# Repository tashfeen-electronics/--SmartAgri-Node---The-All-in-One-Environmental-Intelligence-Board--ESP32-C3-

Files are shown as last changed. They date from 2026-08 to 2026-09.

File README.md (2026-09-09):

# 🌾 SmartAgri Node — The All-in-One Environmental Intelligence Board— ESP32-C3 Environmental Monitoring PCB

A custom 4-layer PCB designed in KiCad for smart agriculture and environmental data logging — built around the **ESP32-C3-WROOM-02-H4**, with onboard sensing, local storage, and off-grid power management.






---

## 🚀 Overview

## 🌾 SmartAgri Node — The All-in-One Environmental Intelligence Board

*A masterclass in compact IoT engineering — built for the field, engineered for the future.*

Powered by the **ESP32-C3-WROOM-02-H4**, this board isn't just a sensor node — it's a complete edge-computing ecosystem packed into a single, elegant design. Whether you're building smart farms, weather networks, or next-gen IoT products, this board is your foundation.

### 🚀 Flagship Applications

- **🌱 Precision Agriculture Systems** — Real-time climate intelligence (temp, humidity, pressure, light) empowers farmers to optimize irrigation, planting, and harvest cycles like never before
- **☀️ Off-Grid Solar Monitoring Stations** — Autonomous, self-charging design (USB-C + battery + MCP73871 power management) means true "install and forget" reliability in remote locations
- **📡 Enterprise-Grade IoT Weather Networks** — Wi-Fi/BLE connectivity turns every unit into a live data point in a scalable, cloud-connected sensor mesh
- **💾 Mission-Critical Data Logging** — Onboard microSD ensures zero data loss, even in connectivity dead zones — perfect for research-grade field studies
- **🔊 Smart Environmental Surveillance** — Integrated mic input opens doors to acoustic monitoring: pest detection, livestock sounds, equipment health diagnostics
- **🔆 Intelligent Light Management** — TEMT6000 sensor enables automated greenhouse shading, grow-light control, and crop exposure analytics
- **🔌 Plug-and-Play Expansion Platform** — I2C/GPIO breakout headers make this a launchpad for custom sensor arrays: soil moisture, pH, EC, CO2, and beyond
- **🛡️ Industrial-Grade Power Protection** — ESD protection, fuse safeguarding, and regulated 3.3V rail deliver rock-solid reliability in harsh outdoor conditions
- **☁️ OTA-Ready Firmware Architecture** — Onboard SPI flash means remote fleets can be updated instantly — no truck rolls, no manual reflashing
- **🎓 Premier Prototyping & Education Platform** — USB-C programming, dedicated BOOT/RESET buttons, and SPI test points make this the go-to dev board for makers, students, and R&D teams alike

### 💎 Why This Board Stands Out

One design. Ten industries. Infinite possibilities — from **precision farming** to **smart cities**, **environmental research** to **industrial IoT**. This isn't just a PCB — it's a **scalable platform** ready to power the next generation of connected, autonomous sensing solutions.

---

## 🌾 Applications

- **Smart agriculture field monitoring** — logs temperature, humidity, pressure, and light intensity across crop fields or greenhouses
- **Solar/battery-powered remote sensor node** — runs unattended in the field, rechargeable via USB-C or solar panel
- **Soil/climate data logging station** — SD card backup for areas with weak or no Wi-Fi coverage
- **IoT weather station** — pushes live BME280 readings to a cloud dashboard or local server
- **Sunlight exposure tracking** — monitors sun exposure for crop growth optimization
- **Acoustic/pest monitoring** — mic input can detect insect activity, animal presence, or equipment sound
- **Expandable sensor hub** — I2C/GPIO headers for adding soil moisture, pH, or EC sensors
- **Battery-backed edge logger** — continues sensing during power outages or disconnection
- **OTA-capable firmware node** — onboard SPI flash supports remote firmware updates
- **General-purpose outdoor IoT dev board** — reusable prototyping platform beyond agriculture

---

## 🧩 Hardware Overview

### 🧠 Core Processing & Connectivity
| Component | Part | Purpose |
|---|---|---|
| U3 | ESP32-C3-WROOM-02-H4 | Main MCU — Wi-Fi/BLE, RISC-V core, chosen for wireless field data transmission without an external radio module |
| U4 | CP2102N | USB-to-UART bridge for programming/serial debug over USB-C |
| U2 | W25Q32JVSSIQ (32Mbit SPI Flash) | Extra non-volatile storage for OTA updates and log buffering |
| J3 | GSD090012SEU (microSD slot) | Local offline data logging when Wi-Fi is unavailable |

### 🌡️ Sensors
| Component | Part | Purpose |
|---|---|---|
| U6 | BME280 | Temperature, humidity & barometric pressure sensing |
| Q1 | TEMT6000X01 | Ambient light intensity sensing for crop exposure analysis |
| U7 | MAX4466EXK | Mic amplifier for acoustic sensing (pest/environmental sound) |

### 🔋 Power Management
| Component | Part | Purpose |
|---|---|---|
| J1 | USB-C (2338792-1) | Primary power/data input |
| J2 | JST connector (B2B-PH-SM4-TB) | Li-ion/LiPo battery input |
| U1 | MCP73871 | Battery charge management + power path — charges while running on USB |
| VR1 | LM1117MPX-3.3 | Regulates supply to a clean 3.3V rail |
| U5 | USBLC6-2SC6 | ESD protection on USB data lines |
| F1 | 0ZCH0110AF2E | Resettable fuse — overcurrent protection |
| Q2, Q3 | BC817 | Power switching/load gating for sleep-mode power savings |
| MK1 | CMC-5042PF-AC | Inductor/choke for power line filtering |

### 🕹️ User Interface
| Component | Part | Purpose |
|---|---|---|
| S1 | BOOT button | Puts ESP32 into flashing/bootloader mode |
| S2 | RESET button | Manual MCU reset |
| D1, D5 | Blue LEDs | Status indicators |
| D2, D6 | Green LEDs | Status indicators |
| D3, D4 | Red LEDs | Fault/error indicators |

### 🔧 Debug & Expansion
| Component | Purpose |
|---|---|
| TP1–TP5 | SPI bus test points (MOSI, MISO, SCLK, CS, CS-SD) for debugging flash/SD card |
| J4 | 4-pin header — I2C expansion (GND/SCL/SDA/3.3V) for external sensors |
| J5 | 5-pin header — additional GPIO/power expansion |

### ⚙️ Passives
- **Capacitors (C1–C25):** Decoupling and bulk capacitance for clean power delivery, especially during Wi-Fi transmit bursts
- **Resistors (R1–R35):** Pull-ups (I2C/reset lines), LED current limiting, and voltage divider/feedback networks

---

## 🧱 PCB Stackup — Why 4 Layers?

This board uses a **4-layer stackup (Signal / GND / PWR / Signal)** instead of a simpler 2-layer design, chosen specifically for better signal integrity given the mix of RF, digital, analog, and power circuitry on one small board.

**Benefits realized:**
- ✅ Dedicated, uninterrupted ground plane — critical for ESP32-C3 RF performance and reducing noise coupling into analog sensors
- ✅ Shorter, controlled return paths for high-speed SPI signals (flash + SD card), reducing EMI and reflections
- ✅ Dedicated power plane for cleaner, lower-impedance power delivery — especially during Wi-Fi TX current spikes
- ✅ Better isolation between noisy switching regulator circuitry and sensitive analog front-end (mic amp, light sensor)
- ✅ Tighter, more professional routing without sacrificing signal quality

---

## 🛠️ Tools Used

- **KiCad** — schematic capture, PCB layout, and 3D visualization

---

## 📸 Board Preview

*(Add board render/photo here)*

---

## 📋 Bill of Materials

Full BOM with quantities and footprints is available in <a href="https://github.com/tashfeen-electronics/--SmartAgri-Node---The-All-in-One-Environmental-Intelligence-Board--ESP32-C3-/blob/main/ESP32%20Project/bom/ibom.html" class="button">BOM</a>

---

## 📄 License

<a href="https://github.com/tashfeen-electronics/--SmartAgri-Node---The-All-in-One-Environmental-Intelligence-Board--ESP32-C3-/blob/main/LICENSE" class="button">
  ***LICENSE***
</a>

---

## 🙌 Author

**Tashfeen Electronics**
Designed with ❤️ in KiCad

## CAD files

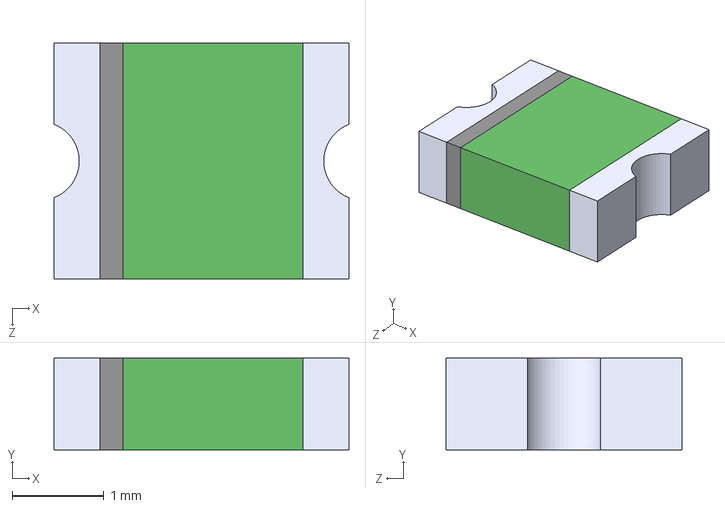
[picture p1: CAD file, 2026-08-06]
ESP32 Project/Symbol and footprint libraries for esp32 project/0ZCH0110AF2E/0ZCH0110AF2E.step
3.21 x 1.00 x 2.58 mm

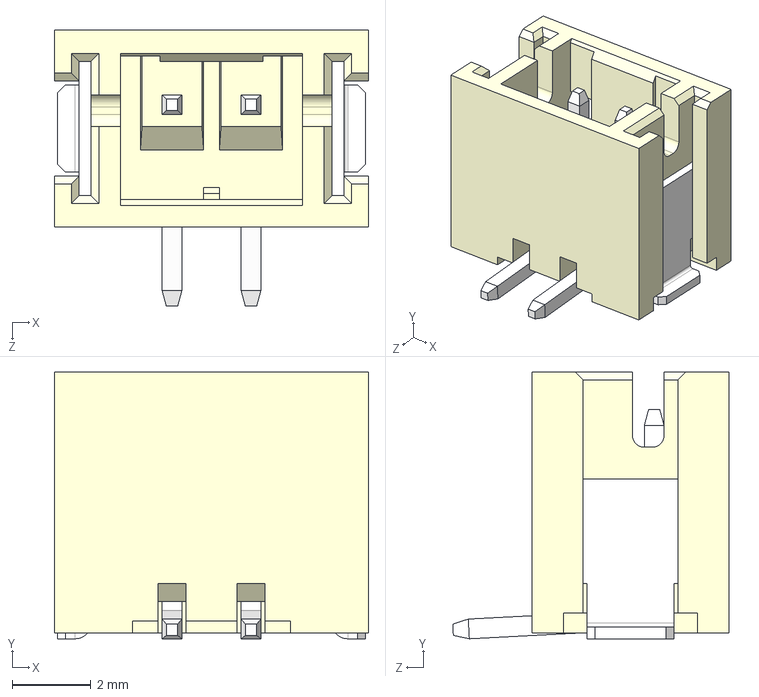
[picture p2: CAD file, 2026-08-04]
ESP32 Project/Symbol and footprint libraries for esp32 project/B2B-PH-SM4-TB/B2B-PH-SM4-TB.step
7.95 x 6.75 x 7.00 mm

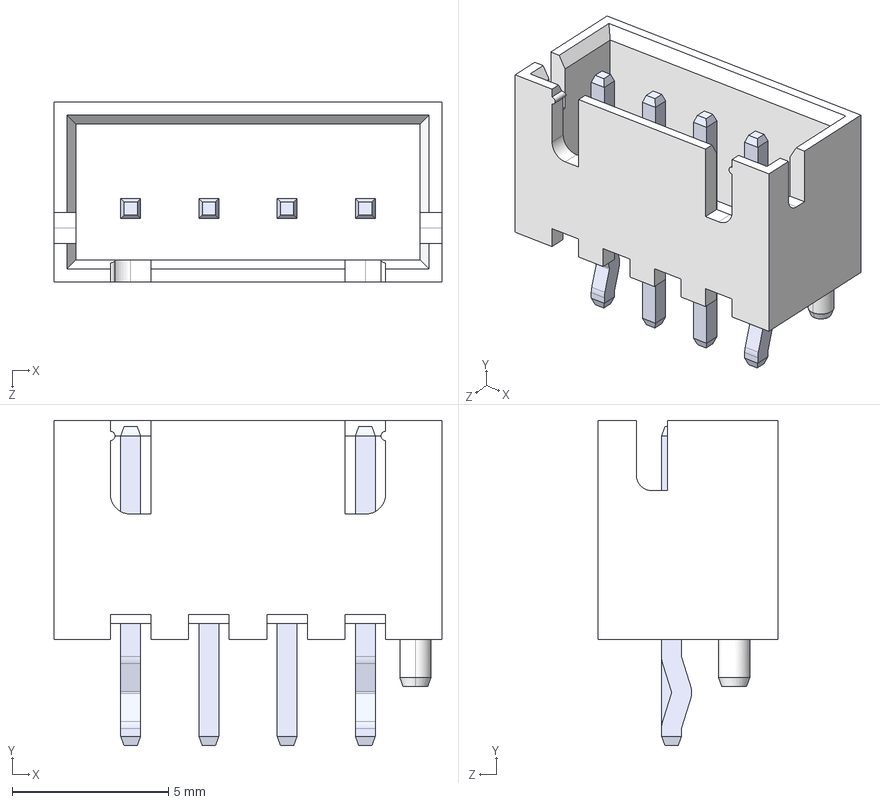
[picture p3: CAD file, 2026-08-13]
ESP32 Project/Symbol and footprint libraries for esp32 project/B4B-XH-AM__LF__SN_/B4B-XH-AM__LF__SN_.step
12.4 x 10.4 x 5.75 mm

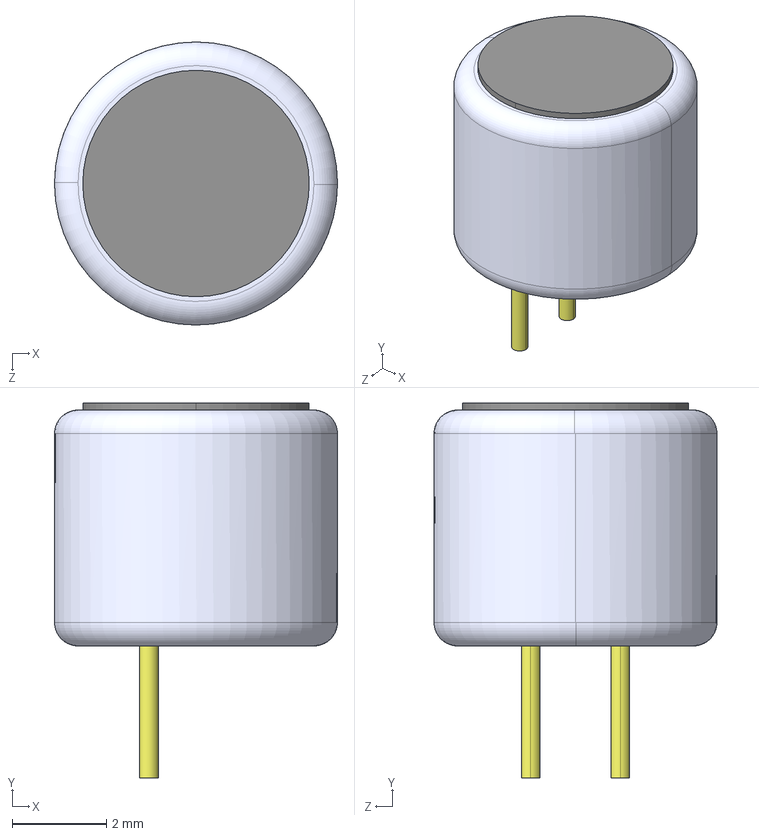
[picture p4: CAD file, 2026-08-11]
ESP32 Project/Symbol and footprint libraries for esp32 project/CMC-5042PF-AC/CMC-5042PF-AC.step
6.00 x 7.95 x 6.00 mm

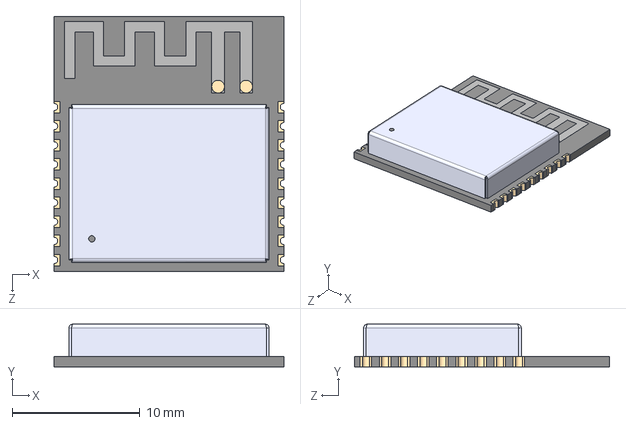
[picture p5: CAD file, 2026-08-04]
ESP32 Project/Symbol and footprint libraries for esp32 project/Esp32 c3 wroom 02/ESP32-C3-WROOM-02-H4.step
18.0 x 3.35 x 20.0 mm

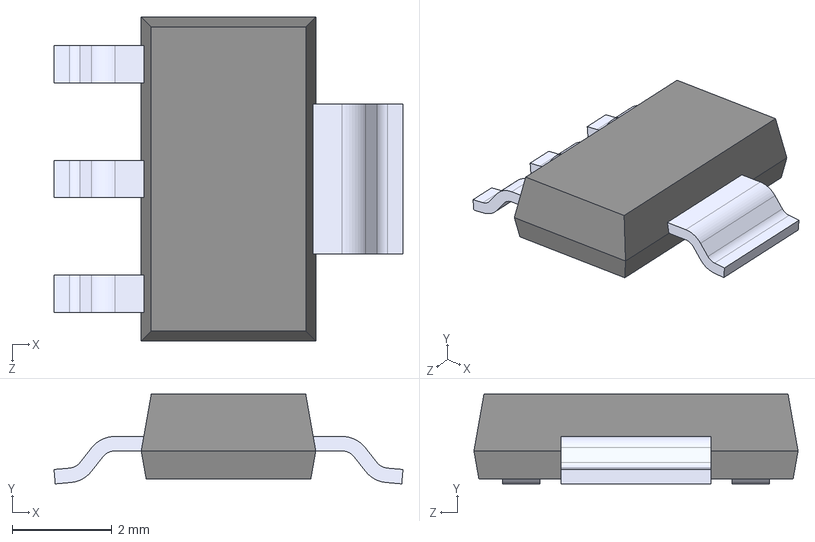
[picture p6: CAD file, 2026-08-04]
ESP32 Project/Symbol and footprint libraries for esp32 project/LM1117MPX-3.3/LM1117MPX-3.3.step
7.00 x 1.80 x 6.50 mm

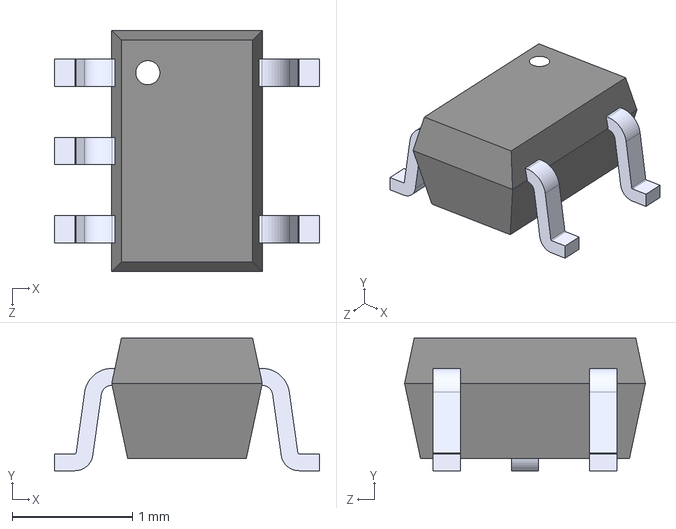
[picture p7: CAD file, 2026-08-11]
ESP32 Project/Symbol and footprint libraries for esp32 project/MAX4466EXK/MAX4466EXK.step
2.20 x 1.10 x 2.00 mm

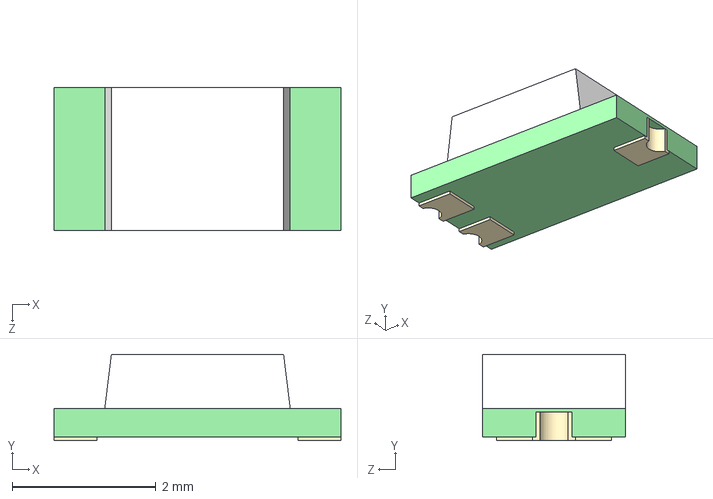
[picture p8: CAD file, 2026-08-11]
ESP32 Project/Symbol and footprint libraries for esp32 project/TEMT6000X01/TEMT6000X01.step
4.00 x 1.20 x 2.00 mm

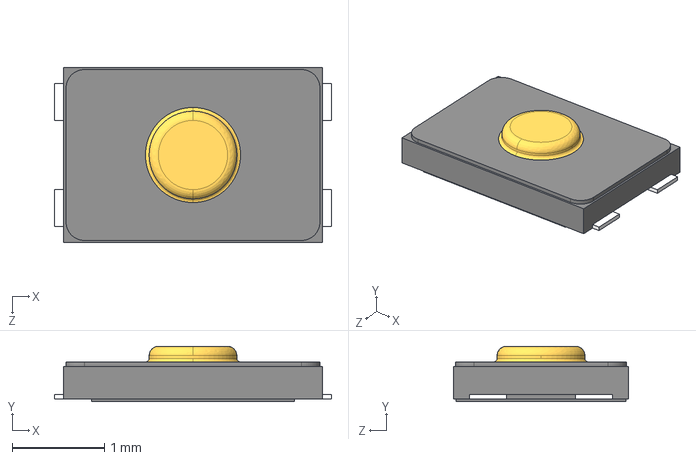
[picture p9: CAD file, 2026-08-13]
ESP32 Project/Symbol and footprint libraries for esp32 project/USLPT2819DT2TR/USLPT2819DT2TR.step
3.00 x 0.6 x 1.90 mm

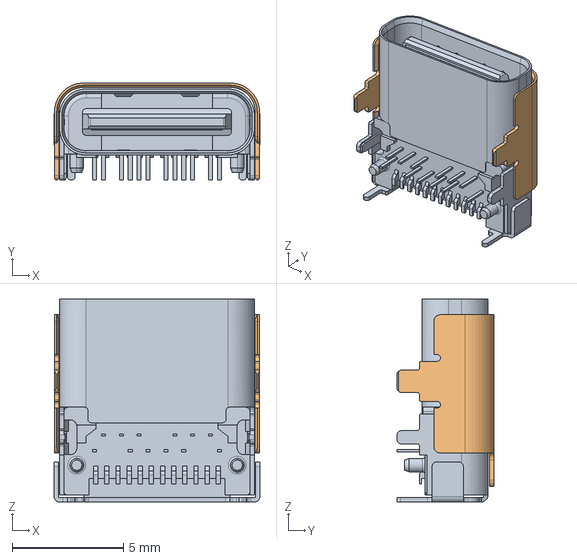
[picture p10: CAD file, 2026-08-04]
ESP32 Project/Symbol and footprint libraries for esp32 project/2338792-1/2338792-1.step
9.24 x 4.35 x 9.10 mm

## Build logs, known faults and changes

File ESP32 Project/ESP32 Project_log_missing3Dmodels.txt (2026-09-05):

[('U4', 'E:\\KICAD v10.4\\share\\kicad\\3dmodels\\Package_DFN_QFN.3dshapes\\QFN-20-1EP_3x3mm_P0.45mm_EP1.6x1.6mm.step')]

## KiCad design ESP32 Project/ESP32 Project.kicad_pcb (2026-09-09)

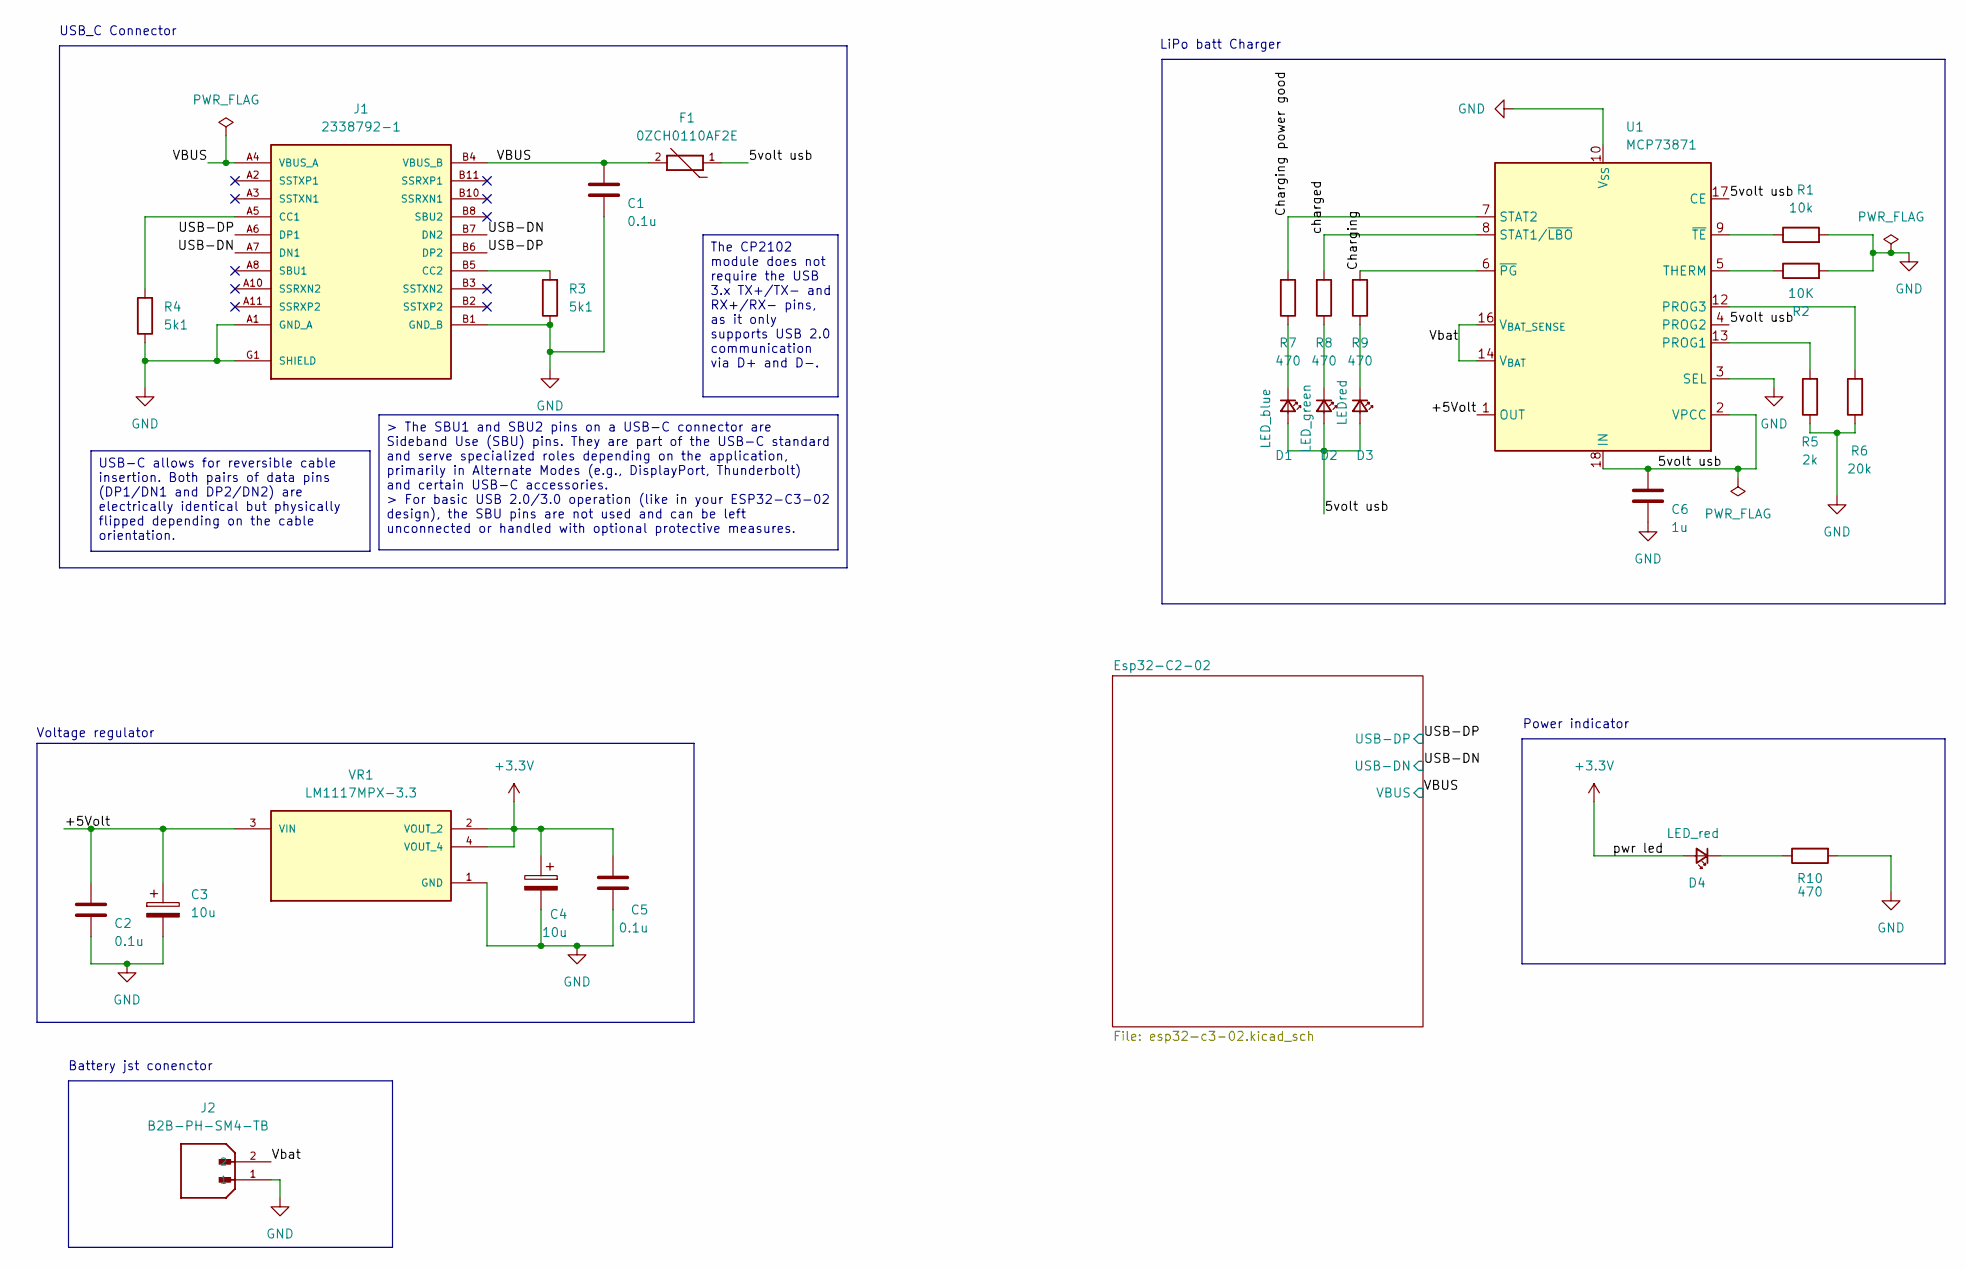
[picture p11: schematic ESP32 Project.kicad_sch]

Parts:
C1, C2, C5: 0.1u; C_0805_2012Metric
C3, C4: 10u; CP_EIA-3216-12_Kemet-S
C6: 1u; C_0805_2012Metric
D1: LED_blue; LED_0805_2012Metric_Pad1.15x1.40mm_HandSolder
D2: LED_green; LED_0805_2012Metric_Pad1.15x1.40mm_HandSolder
D3: LEDred; LED_0805_2012Metric_Pad1.15x1.40mm_HandSolder
D4: LED_red; LED_0805_2012Metric_Pad1.15x1.40mm_HandSolder
F1: 0ZCH0110AF2E; FUSC3225X100N; PARTREV Apr2023
J1: 2338792-1; TE_2338792-1; PARTREV A1
J2: B2B-PH-SM4-TB; JST_B2B-PH-SM4-TB; PARTREV N/A
R1: 10k; R_0805_2012Metric
R2: 10K; R_0805_2012Metric
R3, R4: 5k1; R_0805_2012Metric
R5: 2k; R_0805_2012Metric
R6: 20k; R_0805_2012Metric
R7, R8, R9, R10: 470; R_0805_2012Metric
U1: MCP73871; QFN-20-1EP_4x4mm_P0.5mm_EP2.5x2.5mm
VR1: LM1117MPX-3.3; VREG_LM1117MPX-3.3; PARTREV O

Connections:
+3.3V: C4.1, C5.1, D4.2 (A), VR1.2 (VOUT_2), VR1.4 (VOUT_4); also elsewhere on the board
/5volt usb: C6.1, D1.2 (A), D2.2 (A), D3.2 (A), F1.1, U1.2 (VPCC), U1.4 (PROG2), U1.17 (CE), U1.18 (IN), U1.19 (IN)
/+5Volt: C2.1, C3.1, U1.1 (OUT), U1.20 (OUT), VR1.3 (VIN)
/Charging: R9.2, U1.6 (~PG)
/Charging power good: R7.2, U1.7 (STAT2)
/USB-DN: J1.A7 (DN1), J1.B7 (DN2); also elsewhere on the board
/USB-DP: J1.A6 (DP1), J1.B6 (DP2); also elsewhere on the board
/Vbat: J2.2, U1.14 (V_{BAT}), U1.15 (V_{BAT}), U1.16 (V_{BAT_SENSE})
/charged: R8.2, U1.8 (STAT1/~LBO)
GND: C1.2, C2.2, C3.2, C4.2, C5.2, C6.2, J1.A1 (GND_A), J1.A12 (GND_A), J1.B1 (GND_B), J1.B12 (GND_B), J1.G1 (SHIELD), J1.G2 (SHIELD), J1.G3 (SHIELD), J1.G4 (SHIELD), J1.G5 (SHIELD), J1.G6 (SHIELD), J2.1, R1.2, R2.2, R3.1, R4.1, R5.1, R6.1, R10.2, U1.3 (SEL), U1.10 (V_{SS}), U1.11 (V_{SS}), U1.21 (V_{SS}), VR1.1 (GND); also elsewhere on the board
unnamed: D1.1 (K), R7.1
unnamed: D2.1 (K), R8.1
unnamed: D3.1 (K), R9.1
unnamed: D4.1 (K), R10.1
unnamed: J1.A5 (CC1), R4.2
unnamed: J1.B5 (CC2), R3.2
unnamed: R5.2, U1.13 (PROG1)
unnamed: R6.2, U1.12 (PROG3)
unnamed: R2.1, U1.5 (THERM)
unnamed: R1.1, U1.9 (~TE)
VBUS_A: C1.1, F1.2, J1.A4 (VBUS_A), J1.A9 (VBUS_A), J1.B4 (VBUS_B), J1.B9 (VBUS_B); also elsewhere on the board

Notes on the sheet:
Power indicator
USB_C Connector
Voltage regulator
LiPo batt Charger
Battery jst conenctor
USB-C allows for reversible cable insertion. Both pairs of data pins (DP1/DN1 and DP2/DN2) are electrically identical but physically flipped depending on the cable orientation.
The CP2102 module does not require the USB 3.x TX+/TX- and RX+/RX- pins, as it only supports USB 2.0 communication via D+ and D-.
> The SBU1 and SBU2 pins on a USB-C connector are Sideband Use (SBU) pins. They are part of the USB-C standard and serve specialized roles depending on the application, primarily in Alternate Modes (e.g., DisplayPort, Thunderbolt) and certain USB-C accessories. > For basic USB 2.0/3.0 operation (li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

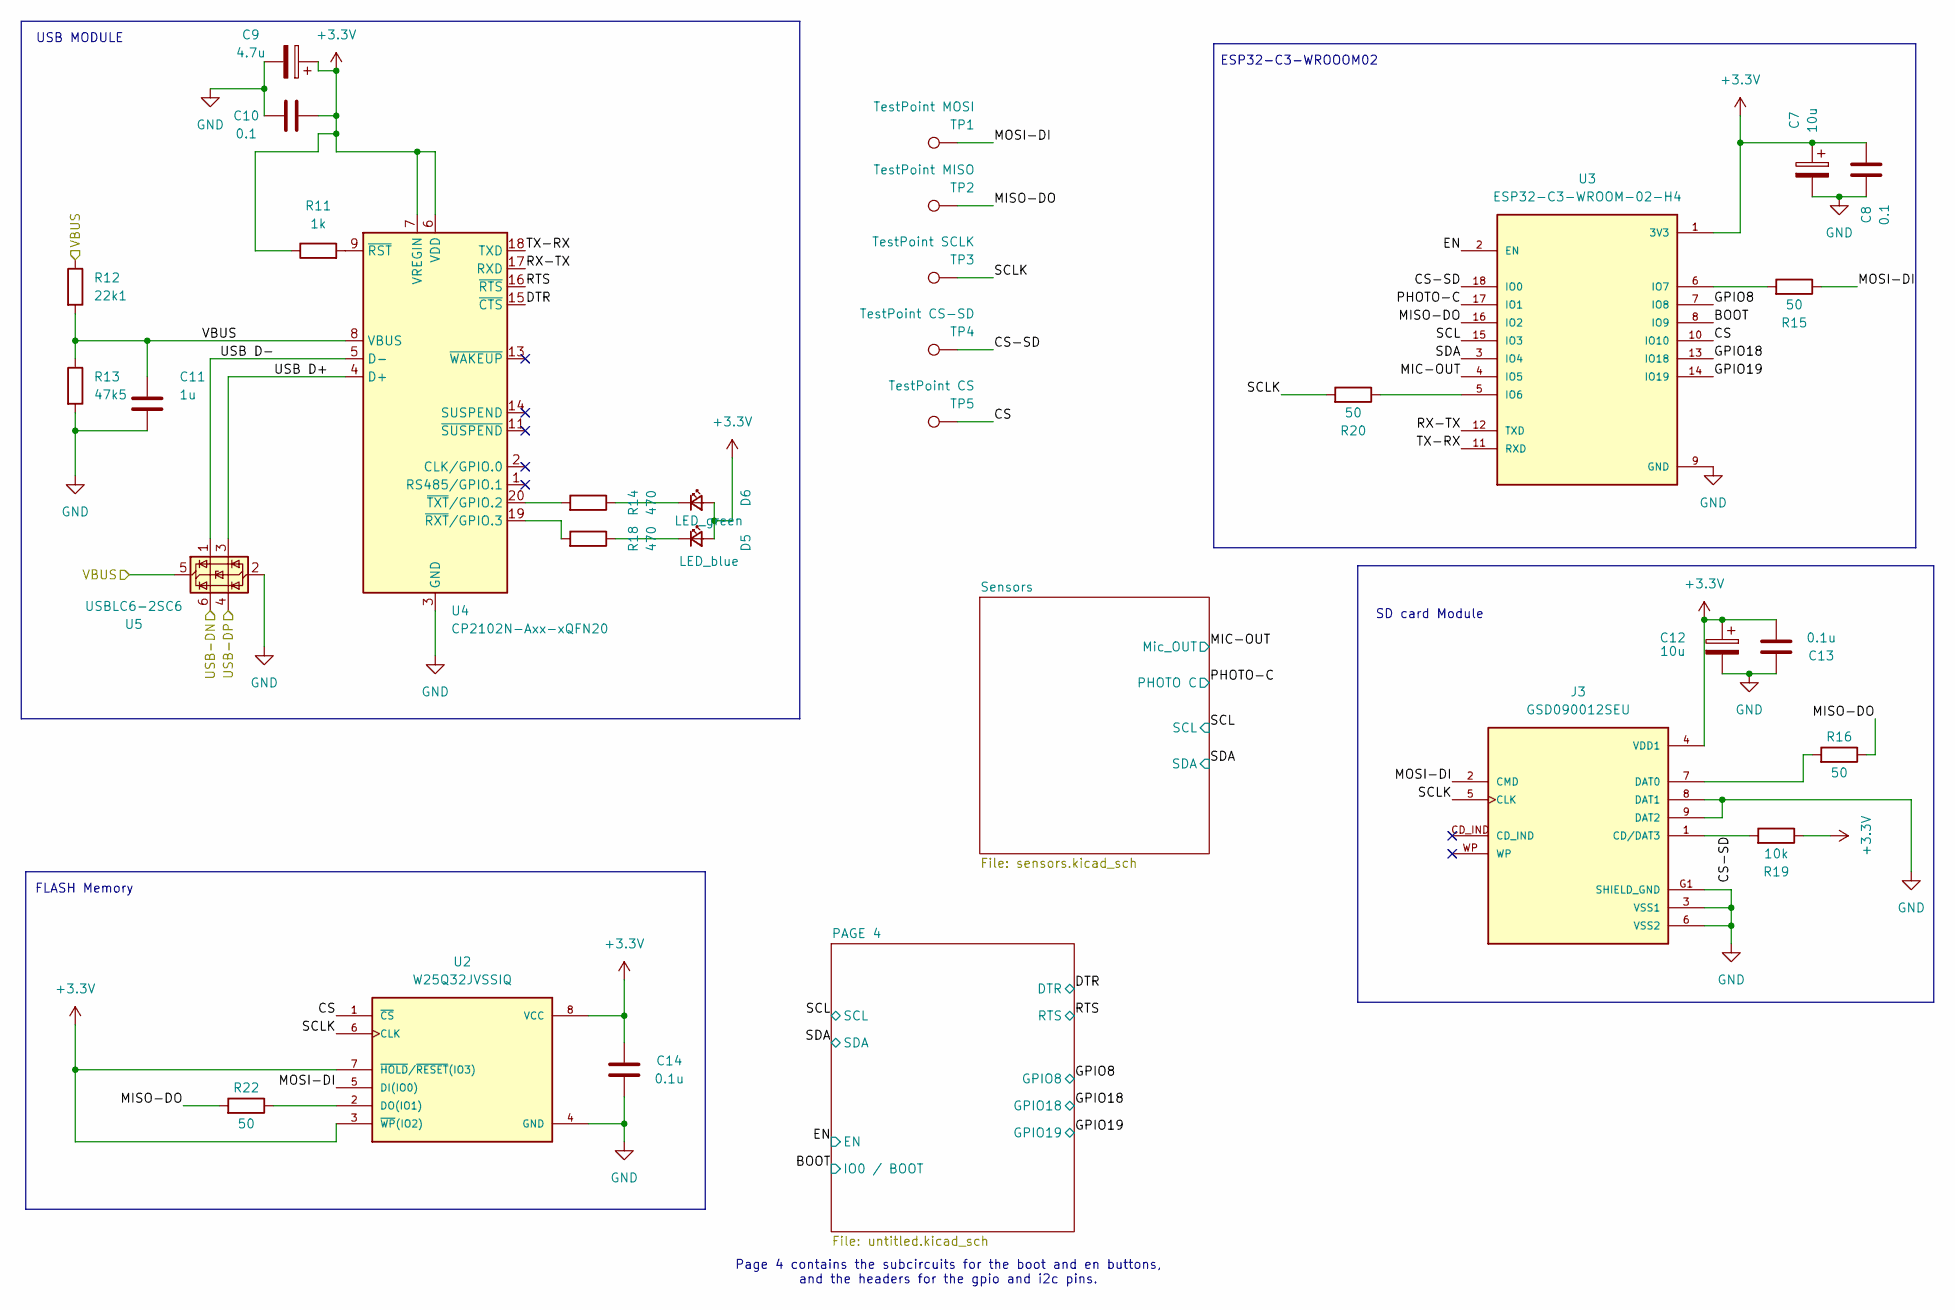
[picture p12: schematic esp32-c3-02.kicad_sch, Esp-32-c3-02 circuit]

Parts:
C7, C12: 10u; CP_EIA-3216-12_Kemet-S
C8, C10: 0.1; C_0805_2012Metric
C9: 4.7u; CP_EIA-3216-12_Kemet-S
C11: 1u; C_0805_2012Metric
C13, C14: 0.1u; C_0805_2012Metric
D5: LED_blue; LED_0805_2012Metric_Pad1.15x1.40mm_HandSolder
D6: LED_green; LED_0805_2012Metric_Pad1.15x1.40mm_HandSolder
J3: GSD090012SEU; AMPHENOL_GSD090012SEU; PARTREV E
R11: 1k; R_0805_2012Metric
R12: 22k1; R_0805_2012Metric
R13: 47k5; R_0805_2012Metric
R14, R18: 470; R_0805_2012Metric
R15, R16, R20, R22: 50; R_0805_2012Metric
R19: 10k; R_0805_2012Metric
TP1: TestPoint MOSI; TestPoint_Pad_D1.0mm
TP2: TestPoint MISO; TestPoint_Pad_D1.0mm
TP3: TestPoint SCLK; TestPoint_Pad_D1.0mm
TP4: TestPoint CS-SD; TestPoint_Pad_D1.0mm
TP5: TestPoint CS; TestPoint_Pad_D1.0mm
U2: W25Q32JVSSIQ; SOIC127P790X216-8N; M_PART_NUMBER W25QXX
U3: ESP32-C3-WROOM-02-H4; MODULE_ESP32-C3-WROOM-02-H4
U4: CP2102N-Axx-xQFN20; QFN-20-1EP_3x3mm_P0.45mm_EP1.6x1.6mm
U5: USBLC6-2SC6; SOT-23-6

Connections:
+3.3V: C7.1, C8.1, C9.1, C10.1, C12.1, C13.1, C14.2, D5.2 (A), D6.2 (A), J3.4 (VDD1), R11.1, R19.1, U2.3 (~WP(IO2)), U2.7 (~HOLD/~RESET(IO3)), U2.8 (VCC), U3.1 (3V3), U4.6 (VDD), U4.7 (VREGIN); also elsewhere on the board
/Esp32-C2-02/BOOT: U3.8 (IO9); also elsewhere on the board
/Esp32-C2-02/CS: TP5.1 (1_1), U2.1 (~CS), U3.10 (IO10)
/Esp32-C2-02/CS-SD: J3.1 (CD/DAT3), R19.2, TP4.1 (1_1), U3.18 (IO0)
/Esp32-C2-02/DTR: U4.15 (~CTS); also elsewhere on the board
/Esp32-C2-02/EN: U3.2 (EN); also elsewhere on the board
/Esp32-C2-02/GPIO8: U3.7 (IO8); also elsewhere on the board
/Esp32-C2-02/GPIO18: U3.13 (IO18); also elsewhere on the board
/Esp32-C2-02/GPIO19: U3.14 (IO19); also elsewhere on the board
/Esp32-C2-02/MIC-OUT: U3.4 (IO5); also elsewhere on the board
/Esp32-C2-02/MISO-DO: R16.1, R22.2, TP2.1 (1_1), U3.16 (IO2)
/Esp32-C2-02/MOSI-DI: J3.2 (CMD), R15.1, TP1.1 (1_1), U2.5 (DI(IO0))
/Esp32-C2-02/PHOTO-C: U3.17 (IO1); also elsewhere on the board
/Esp32-C2-02/RTS: U4.16 (~RTS); also elsewhere on the board
/Esp32-C2-02/RX-TX: U3.12 (TXD), U4.17 (RXD)
/Esp32-C2-02/SCL: U3.15 (IO3); also elsewhere on the board
/Esp32-C2-02/SCLK: J3.5 (CLK), R20.2, TP3.1 (1_1), U2.6 (CLK)
/Esp32-C2-02/SDA: U3.3 (IO4); also elsewhere on the board
/Esp32-C2-02/TX-RX: U3.11 (RXD), U4.18 (TXD)
/Esp32-C2-02/USB D+: U4.4 (D+), U5.3 (I/O2)
/Esp32-C2-02/USB D-: U4.5 (D-), U5.1 (I/O1)
/USB-DN: U5.6 (I/O1); also elsewhere on the board
/USB-DP: U5.4 (I/O2); also elsewhere on the board
GND: C7.2, C8.2, C9.2, C10.2, C11.2, C12.2, C13.2, C14.1, J3.3 (VSS1), J3.6 (VSS2), J3.8 (DAT1), J3.9 (DAT2), J3.G1 (SHIELD_GND), J3.G2 (SHIELD_GND), J3.G3 (SHIELD_GND), J3.G4 (SHIELD_GND), R13.2, U2.4 (GND), U3.9 (GND), U3.19 (GND), U3.20 (GND), U3.21 (GND), U3.22 (GND), U3.23 (GND), U3.24 (GND), U3.25 (GND), U3.26 (GND), U3.27 (GND), U3.28 (GND), U3.29 (GND), U3.30 (GND), U3.31 (GND), U3.32 (GND), U3.33 (GND), U3.34 (GND), U3.35 (GND), U3.36 (GND), U3.37 (GND), U3.38 (GND), U3.39 (GND), U4.3 (GND), U4.12 (GND), U4.21 (GND), U5.2 (GND); also elsewhere on the board
unnamed: D5.1 (K), R18.1
unnamed: D6.1 (K), R14.1
unnamed: J3.7 (DAT0), R16.2
unnamed: R22.1, U2.2 (DO(IO1))
unnamed: R20.1, U3.5 (IO6)
unnamed: R15.2, U3.6 (IO7)
unnamed: R11.2, U4.9 (~RST)
unnamed: R18.2, U4.19 (~RXT/GPIO.3)
unnamed: R14.2, U4.20 (~TXT/GPIO.2)
VBUS_A: C11.1, R12.1, R12.2, R13.1, U4.8 (VBUS), U5.5 (VBUS); also elsewhere on the board

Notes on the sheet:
USB MODULE
SD card Module
Page 4 contains the subcircuits for the boot and en buttons, and the headers for the gpio and i2c pins.
ESP32-C3-WROOOM02
FLASH Memory

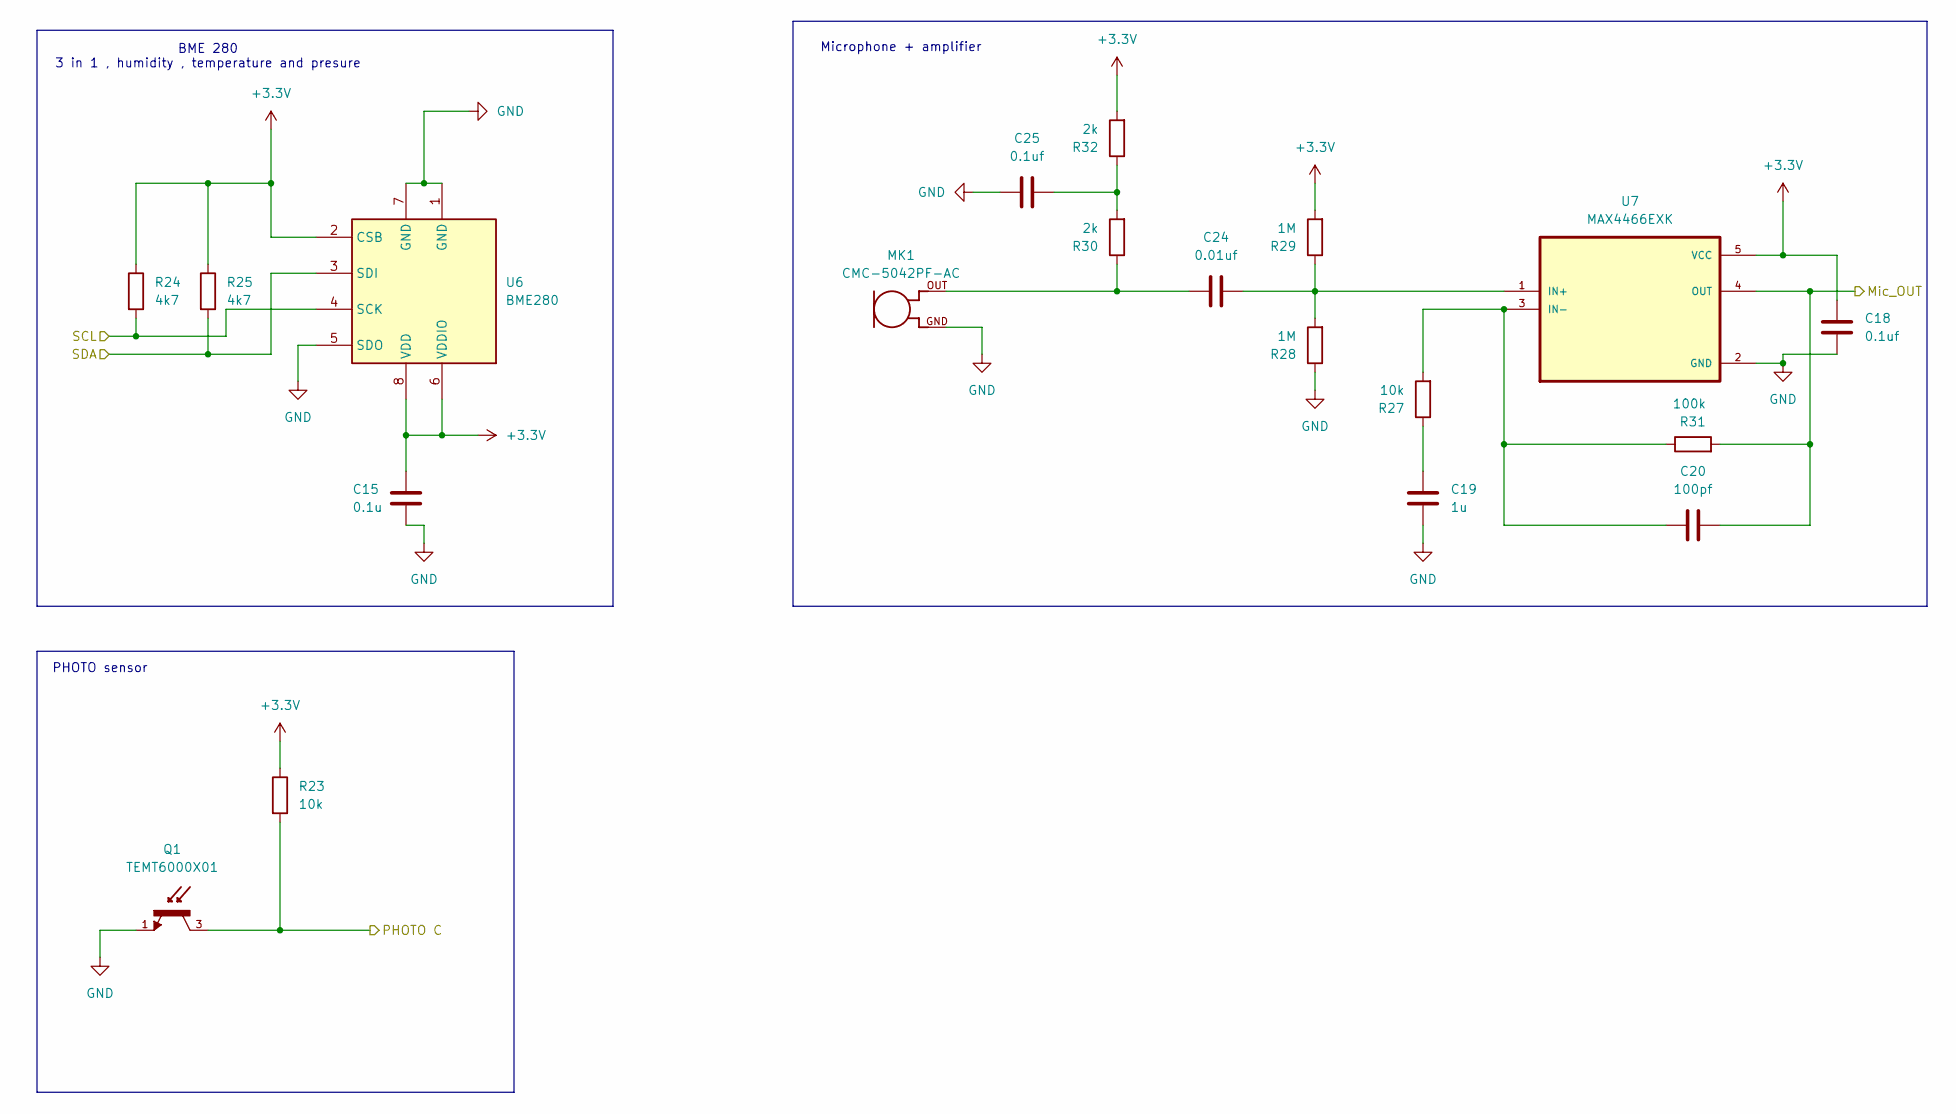
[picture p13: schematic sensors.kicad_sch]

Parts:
C15: 0.1u; C_0805_2012Metric
C18, C25: 0.1uf; C_0805_2012Metric
C19: 1u; C_0805_2012Metric
C20: 100pf; C_0805_2012Metric
C24: 0.01uf; C_0805_2012Metric
MK1: CMC-5042PF-AC; CUI_CMC-5042PF-AC
Q1: TEMT6000X01; TRANS_TEMT6000X01; PARTREV 1.9
R23, R27: 10k; R_0805_2012Metric
R24, R25: 4k7; R_0805_2012Metric
R28, R29: 1M; R_0805_2012Metric
R30, R32: 2k; R_0805_2012Metric
R31: 100k; R_0805_2012Metric
U6: BME280; Bosch_LGA-8_2.5x2.5mm_P0.65mm_ClockwisePinNumbering
U7: MAX4466EXK; SOT65P210X110-5N; DigiKey_Part_Number MAX4466EXK+CT-ND

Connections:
+3.3V: C15.2, C18.2, R23.1, R24.1, R25.1, R29.2, R32.2, U6.2 (CSB), U6.6 (VDDIO), U6.8 (VDD), U7.5 (VCC); also elsewhere on the board
/Esp32-C2-02/MIC-OUT: C20.1, R31.2, U7.4 (OUT); also elsewhere on the board
/Esp32-C2-02/PHOTO-C: Q1.3, R23.2; also elsewhere on the board
/Esp32-C2-02/SCL: R24.2, U6.4 (SCK); also elsewhere on the board
/Esp32-C2-02/SDA: R25.2, U6.3 (SDI); also elsewhere on the board
GND: C15.1, C18.1, C19.2, C25.2, MK1.GND, Q1.1, R28.1, U6.1 (GND), U6.5 (SDO), U6.7 (GND), U7.2 (GND); also elsewhere on the board
unnamed: C19.1, R27.1
unnamed: C24.2, MK1.OUT, R30.1
unnamed: C25.1, R30.2, R32.1
unnamed: C24.1, R28.2, R29.1, U7.1 (IN+)
unnamed: C20.2, R27.2, R31.1, U7.3 (IN-)

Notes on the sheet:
BME 280 3 in 1 , humidity , temperature and presure
PHOTO sensor
Microphone + amplifier

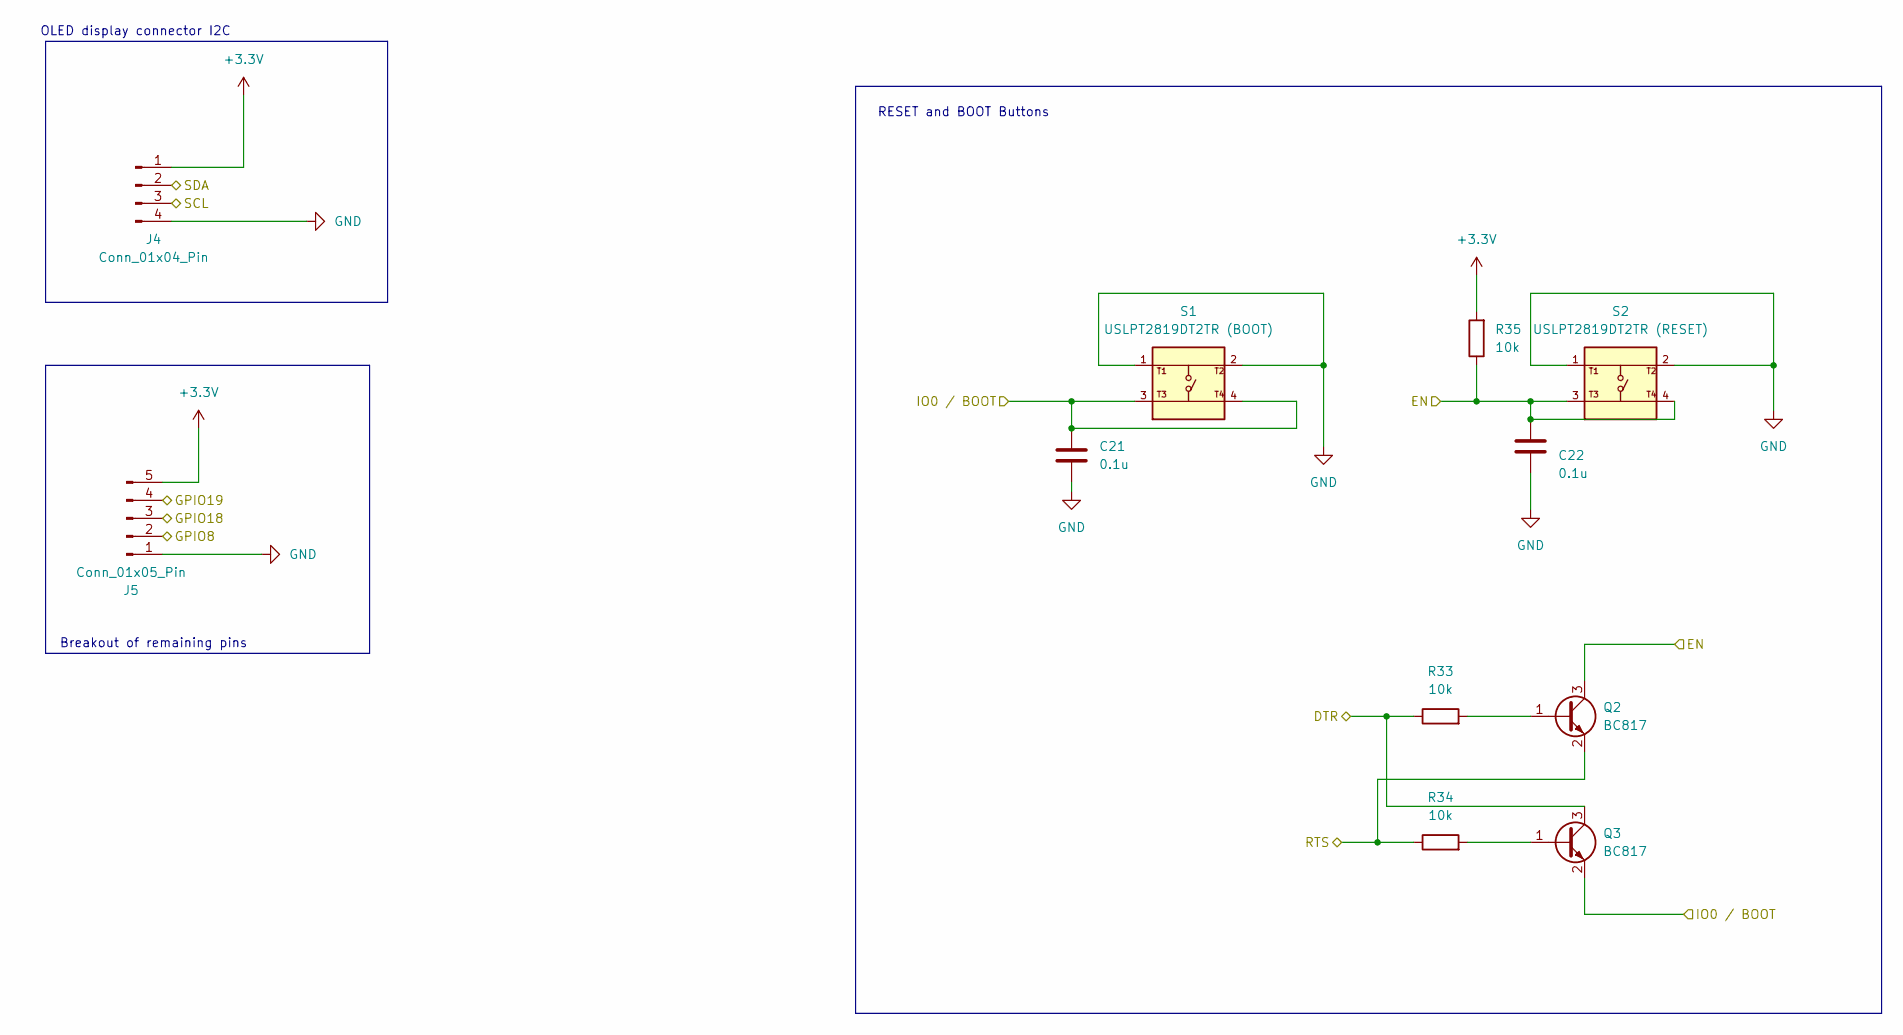
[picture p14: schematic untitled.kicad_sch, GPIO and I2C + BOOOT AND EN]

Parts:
C21, C22: 0.1u; C_0805_2012Metric
J4: Conn_01x04_Pin; PinHeader_1x04_P2.54mm_Vertical
J5: Conn_01x05_Pin; PinHeader_1x05_P2.54mm_Vertical
Q2, Q3: BC817; SOT-23
R33, R34, R35: 10k; R_0805_2012Metric
S1: USLPT2819DT2TR (BOOT); SW_USLPT2819DT2TR; PARTREV P
S2: USLPT2819DT2TR (RESET); SW_USLPT2819DT2TR; PARTREV P

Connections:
+3.3V: J4.1, J5.5, R35.2; also elsewhere on the board
/Esp32-C2-02/BOOT: C21.1, Q3.2 (E), S1.3, S1.4; also elsewhere on the board
/Esp32-C2-02/DTR: Q3.3 (C), R33.1; also elsewhere on the board
/Esp32-C2-02/EN: C22.1, Q2.3 (C), R35.1, S2.3, S2.4; also elsewhere on the board
/Esp32-C2-02/GPIO8: J5.2; also elsewhere on the board
/Esp32-C2-02/GPIO18: J5.3; also elsewhere on the board
/Esp32-C2-02/GPIO19: J5.4; also elsewhere on the board
/Esp32-C2-02/RTS: Q2.2 (E), R34.1; also elsewhere on the board
/Esp32-C2-02/SCL: J4.3; also elsewhere on the board
/Esp32-C2-02/SDA: J4.2; also elsewhere on the board
GND: C21.2, C22.2, J4.4, J5.1, S1.1, S1.2, S2.1, S2.2; also elsewhere on the board
unnamed: Q2.1 (B), R33.2
unnamed: Q3.1 (B), R34.2

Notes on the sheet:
RESET and BOOT Buttons
OLED display connector I2C
Breakout of remaining pins

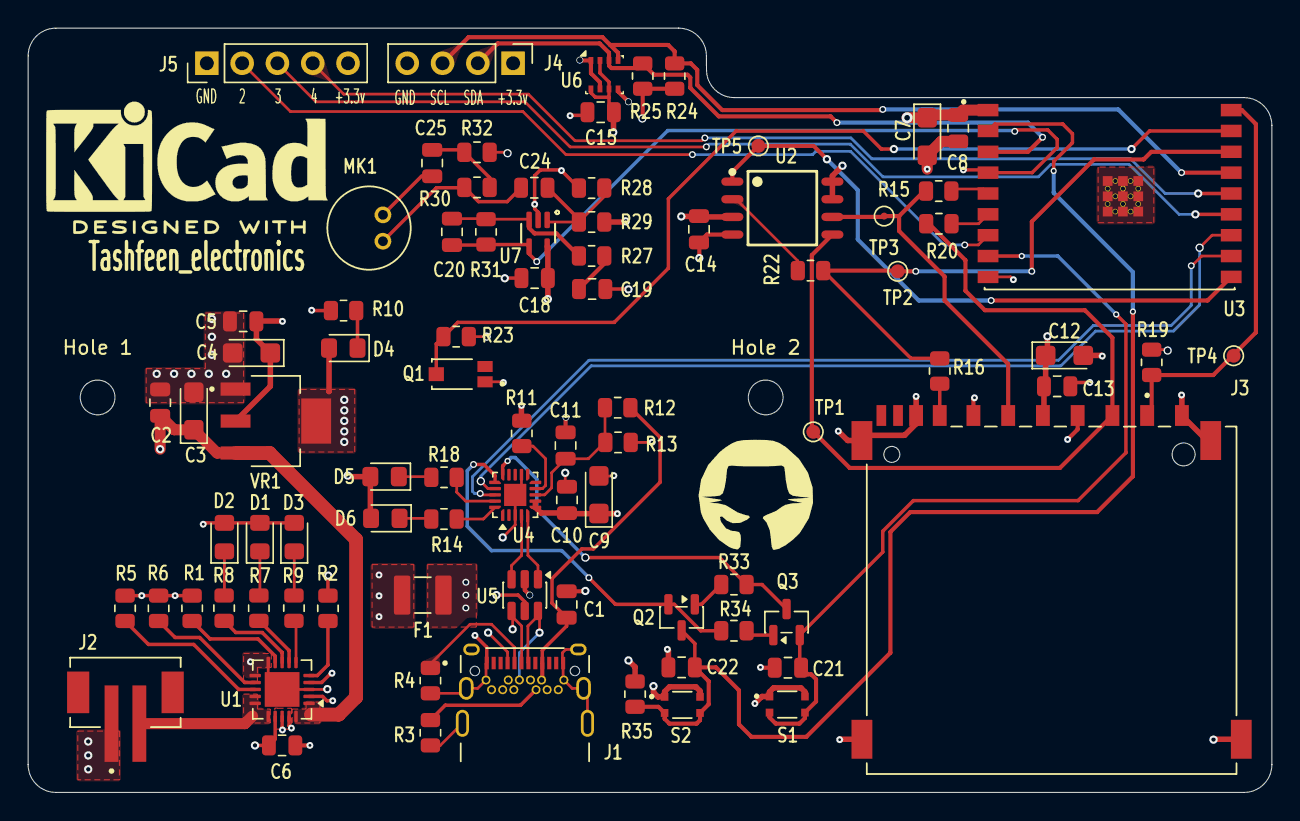
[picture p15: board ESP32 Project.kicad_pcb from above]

Board: 4 copper layers, 89.5 x 55.0 mm, 87 parts (0 on the bottom side), 57 nets.

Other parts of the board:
Hole 1, Hole 2: MountingHole_2.5mm

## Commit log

2026-08-03 initial working and checking
    [ESP32 Project.kicad_pcb, ESP32 Project.kicad_sch]
2026-08-03 frist day
    [ESP32 Project.kicad_pcb]
2026-08-04 something more done
    [2338792-1.step, B2B-PH-SM4-TB.step, ESP32 Project.kicad_pcb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]
2026-08-06 lipo charger + usb c connector + voltage regulator schema done
    [0ZCH0110AF2E.step, ESP32 Project.kicad_sch]
2026-08-06 schema saved
    [ESP32 Project.kicad_sch]
2026-08-07 esp 32 symbols and footprint got edit and more work have done
    [ESP32 Project.kicad_pcb, ESP32 Project.kicad_sch, esp32-c3-02.kicad_sch]
2026-08-08 most of the schema is done , esp32 page is done
    [ESP32 Project.kicad_sch, esp32-c3-02.kicad_sch, sensors.kicad_sch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]
2026-08-11 new loc
    [CMC-5042PF-AC.step, MAX4466EXK.step, TEMT6000X01.step]
2026-08-11 little bit of work done like bm280
    [sensors.kicad_sch]
2026-08-13 we are at edge of work , almost complete and now going for the pcb design and routign
    [B4B-XH-AM__LF__SN_.step, USLPT2819DT2TR.step, esp32-c3-02.kicad_sch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]
2026-08-14 schema is done
    [0ZCH0110AF2E.step, ESP32 Project.kicad_pcb, ESP32 Project.kicad_sch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]
2026-08-16 something done lmao
    [ESP32 Project.kicad_pcb, ESP32 Project.kicad_sch, esp32-c3-02.kicad_sch]
2026-08-17 pcb ont he way tomoroow
    [ESP32 Project.kicad_pcb, ESP32 Project.kicad_sch, esp32-c3-02.kicad_sch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]
2026-08-18 pcb done and some 3d models aadd
    [ESP32 Project.kicad_pcb, ESP32 Project.kicad_sch, esp32-c3-02.kicad_sch]
2026-08-19 half pcb done
    [ESP32 Project.kicad_pcb]
2026-08-20 Half and more pcb done
    [ESP32 Project.kicad_pcb]
2026-08-22 done more work on pcblayout
    [ESP32 Project.kicad_pcb]
2026-08-30 some have done
    [ESP32 Project.kicad_pcb]
2026-09-03 going to be end
    [ESP32 Project.kicad_pcb]
2026-09-05 tomorrow is gonna be complete
    [ESP32 Project.kicad_pcb, esp32-c3-02.kicad_sch]
2026-09-08 pcb tomoroow is gonna be done
    [ESP32 Project.kicad_pcb]
2026-09-09 Agri node has comes to life!
    [ESP32 Project.kicad_pcb]
